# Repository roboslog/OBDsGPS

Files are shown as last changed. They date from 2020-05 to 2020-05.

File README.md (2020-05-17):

# OBDsGPS

OBD ii GPS tracker is the most convenient vehicle GPS tracking device. This tracker plugs into a vehicle’s OBD II port for easy installation. The OBD ii tracker installs within seconds and runs itself. OBD tracker can be used in any car or van manufactured after 2000.

Why we need OBD?

SPEED ALERT BETA
 “The device can be set to alert you when the vehicle exceeds the posted speed limit of whatever road it is currently travelling on.

SPEED THRESHOLD
 The device can be set to alert you whenever the vehicle exceeds a certain speed.

HARSH BRAKING
 The device tracks the rate of deceleration of the vehicle, a major indicator of aggressive driving, and alerts you when the vehicle exceeds a safe threshold.

RAPID ACCELERATION
Another major indicator of aggressive driving, the device also tracks the rate of acceleration of the vehicle and alerts you when the vehicle exceeds a safe threshold.”

OBD-II Background
The OBD-II specification is controlled by the Society of Automobile Engineers and defines the method for requesting diagnostic data and provides a list of standard parameters from the engine control unit. The specification was first released in 1979. Today, depending upon the vehicle, the tracker can retrieve values that include: throttle, engine RPM, fuel available. In some vehicles, the device can even retrieve engine diagnostic codes.

Where is my OBD-II Port?
The OBD-II diagnostic port, also known as a Data Link Connector (DLC), is generally located on the driver’s side of the car or truck under the dash. The location will vary between different manufacturers, models, and production years of a car or truck model. 

Testing Tracking Device Installation
With the creation of your account, a username and password were sent to you for our tracking website. Logon to the system and go to the reports section. Run the unit list view report. Check to be sure the tracking device is reporting ignition on/off events.

What else OBD can do ?
1.Read error diagnostic code

2.Clear the fault code (clear the error code and turn off MIL)

3.Engine revolutions per minute (RPM)

4.Calculated load value

5.Coolant temperature

6.Fuel system status

7.Speed

8.Short-term fuel situation

9.Long-term fuel situation

10.Intake manifold pressure

11.Fuel injection advance time

12.Intake air temperature

& Many more….

Our all files & Code here are For Non-Commercial (Educational) use Only, For Commercial Use: Give Credit to ROBOSLOG
Thanks
More updates coming soon..

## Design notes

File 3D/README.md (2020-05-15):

1.Read error diagnostic code
2.Clear the fault code (clear the error code and turn off MIL)
3.Engine revolutions per minute (RPM)
4.Calculated load value
5.Coolant temperature
6.Fuel system status
7.Speed
8.Short-term fuel situation
9.Long-term fuel situation
10.Intake manifold pressure
11.Fuel injection advance time
12.Intake air temperature
13.Air flow rate
14.Throttle absolute position
15.Oxygen detection voltage associated with short-term fuel state
16.Fuel system status
17.Fuel pressure
18.Fuel consumption monitoring, etc.

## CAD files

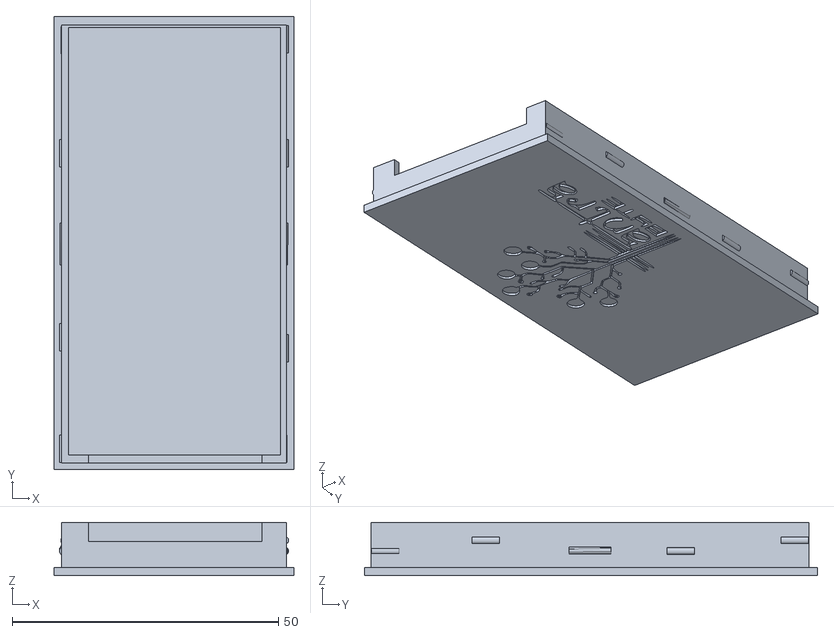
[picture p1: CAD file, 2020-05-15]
3D/obd_topv2.stl
45.0 x 85.0 x 10.0

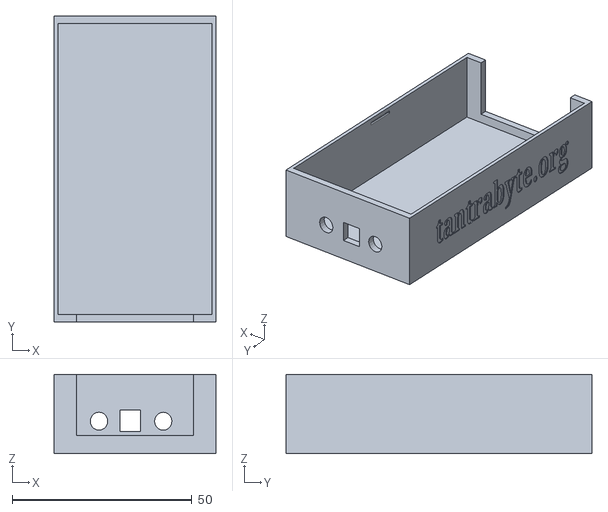
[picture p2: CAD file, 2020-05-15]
3D/obd_bootom v2.stl
45.0 x 85.0 x 22.0

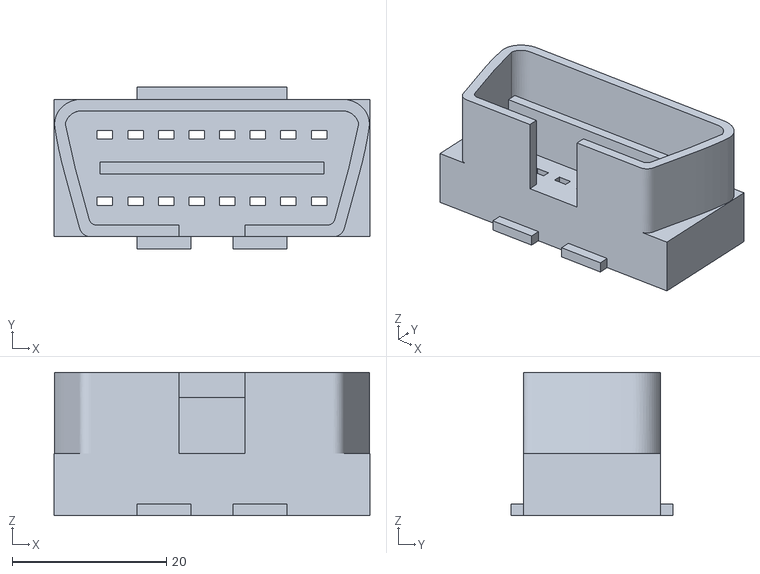
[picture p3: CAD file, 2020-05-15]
3D/OBD.stl
40.9 x 21.0 x 18.5

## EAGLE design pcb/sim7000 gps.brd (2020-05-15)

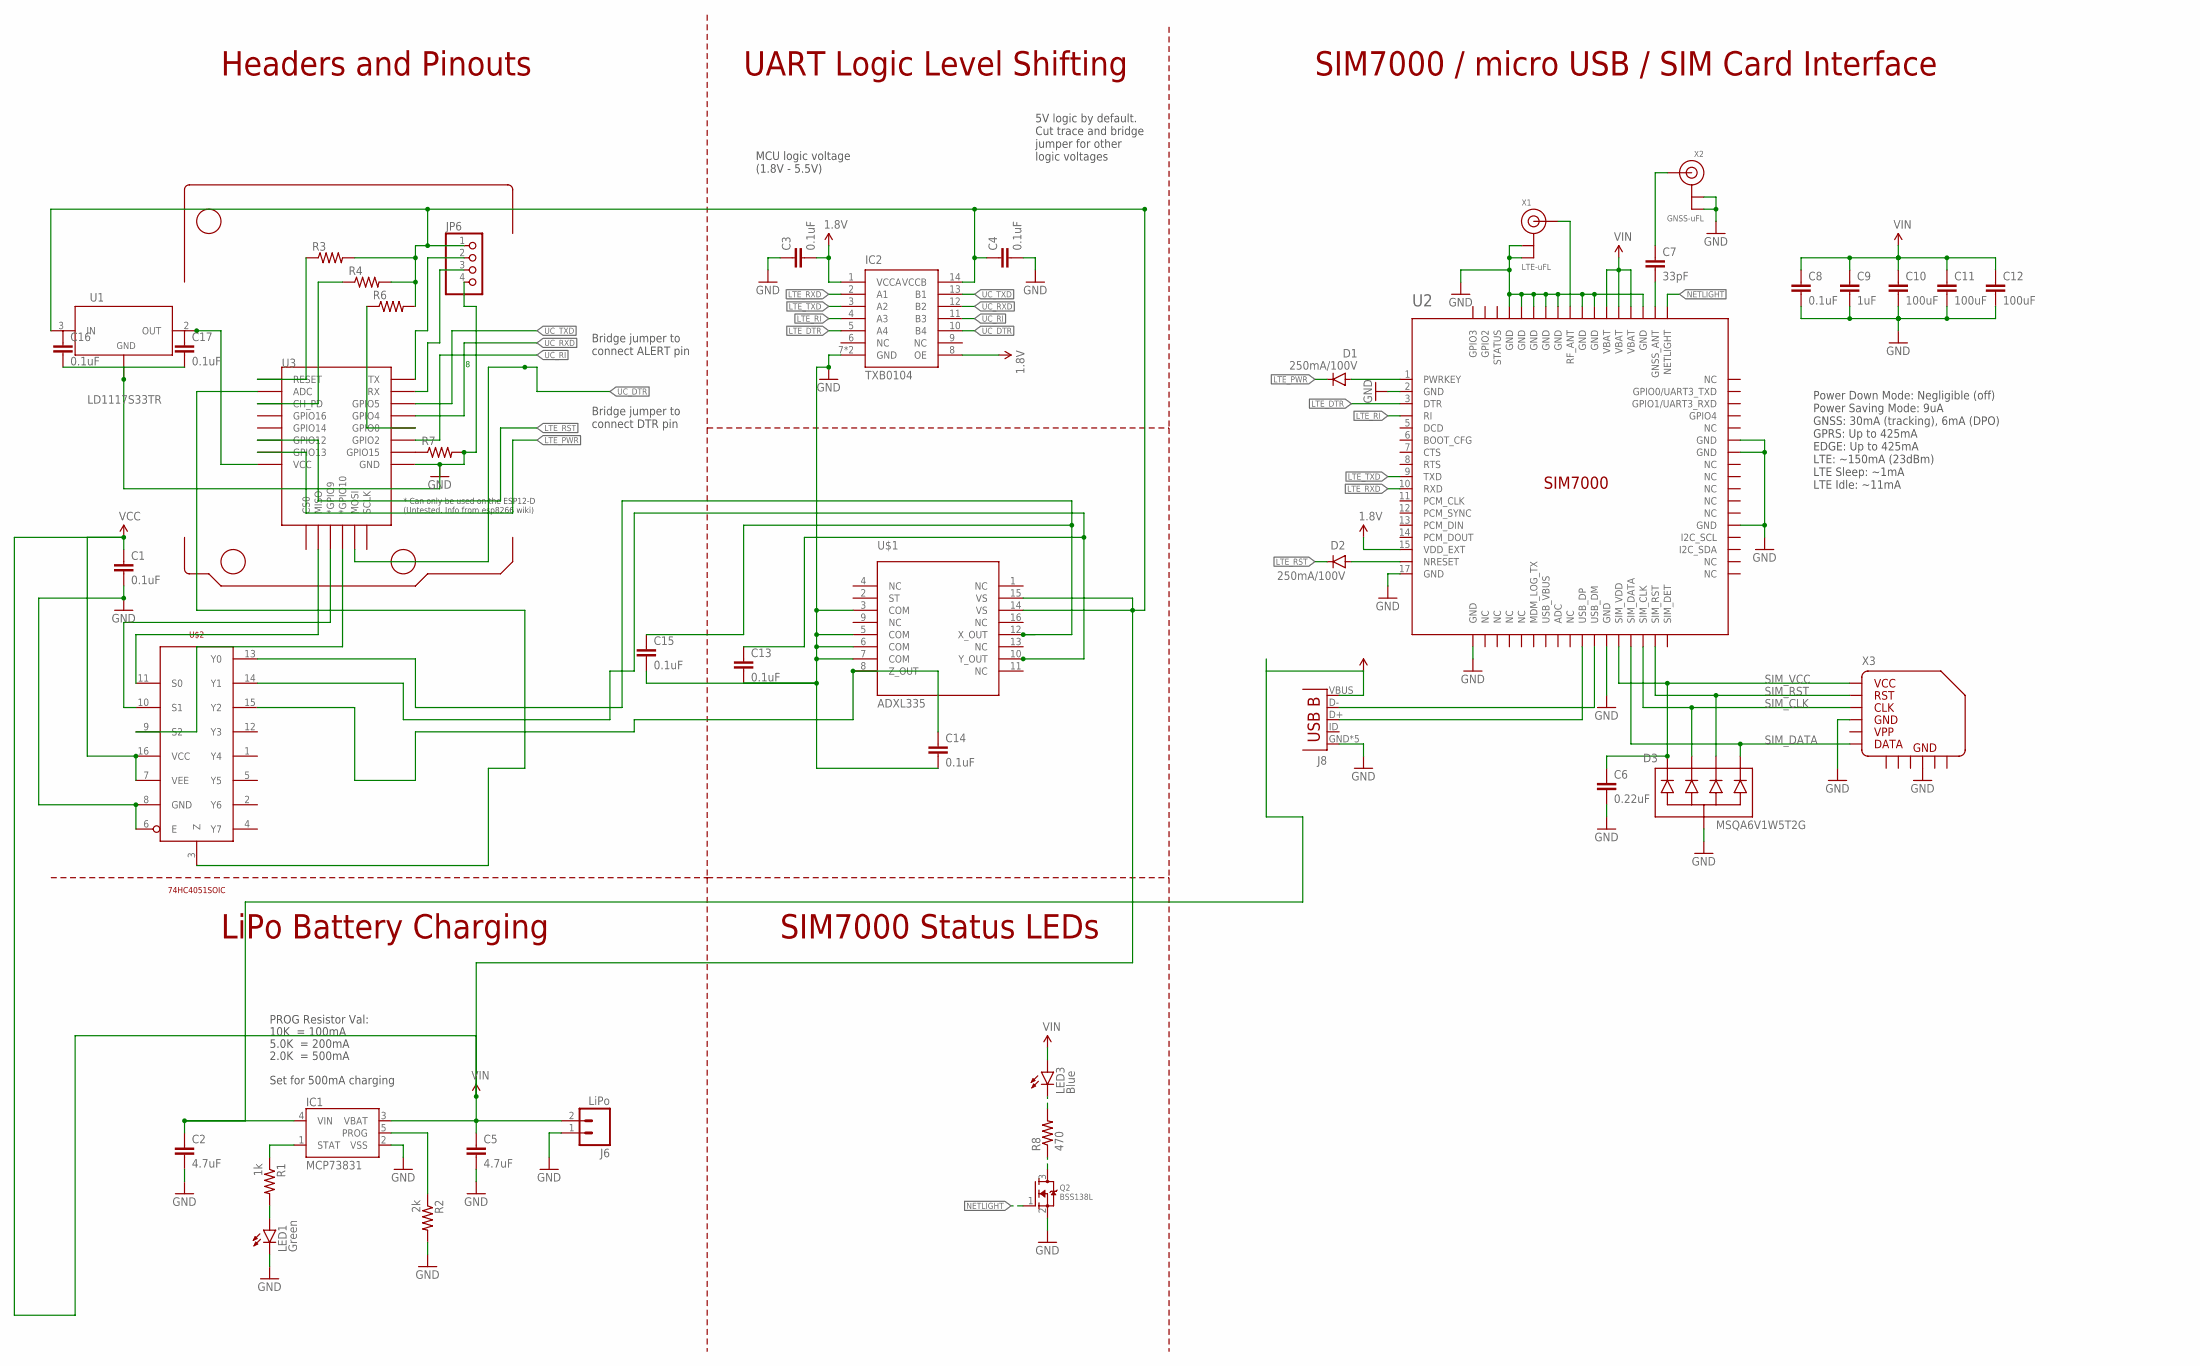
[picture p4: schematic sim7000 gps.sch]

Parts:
C1, C16, C17: 0.1uF; 0603
C2, C5: 4.7uF; 0603-CAP-MARKED
C3, C4, C8, C13, C14, C15: 0.1uF; 0603-CAP-MARKED
C6: 0.22uF; 0603-CAP-MARKED
C7: 33pF; 0603-CAP-MARKED
C9: 1uF; 0603-CAP-MARKED
C10, C11, C12: 100uF; 1210
D1, D2: 250mA/100V; SOD-323
D3: MSQA6V1W5T2G; SOT-353
IC1: MCP73831; SOT23-5
IC2: TXB0104; VQFN-14
J6: LiPo; JST-2-SMD
J8: microUSB; USB-B-MICRO-SMD
JP6: PINHD-1X4; 1X04
LED1: Green; LED-0603-MARKED
LED3: Blue; LED-0603-MARKED
Q2: BSS138L; SOT23-3
R1: 1k; 0603-RES-MARKED
R2: 2k; 0603-RES-MARKED
R3, R4, R6, R7: R-US_R0603; R0603
R8: 470; 0603-RES-MARKED
U1: LD1117S33TR; SOT-223
U2: SIM7000
U3: ESP12ESMD; ESP12E-SMD
U$1: ADXL335; LFCSP16
U$2: 74HC4051SOIC; SOIC-16_3.9MM
X1: LTE-uFL; U.FL
X2: GNSS-uFL; U.FL
X3: MICROSIM_SOCKET_PUSH-PULL

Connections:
1.8V: C3.2, IC2.1 (VCCA), IC2.8 (OE), U2.15 (VDD_EXT)
GND: C1.2, C2.2, C3.1, C4.2, C5.2, C6.2, C8.2, C9.2, C10.2, C11.2, C12.2, C13.2, C14.2, C15.2, C16.2, C17.2, D3.2 (COM), IC1.2 (VSS), IC2.7 (GND), IC2.PAD (GND), J6.1 (2), J8.GND, J8.SHIELD1 (GND), J8.SHIELD2 (GND), J8.SHIELD3 (GND), J8.SHIELD4 (GND), JP6.4, LED1.C, Q2.2 (S), R2.2, R7.2, U1.1 (ADJ/GND), U2.2 (GND), U2.17 (GND), U2.18 (GND), U2.29 (GND), U2.39 (GND), U2.45 (GND), U2.46 (GND), U2.54 (GND), U2.58 (GND), U2.59 (GND), U2.61 (GND), U2.62 (GND), U2.63 (GND), U2.64 (GND), U2.65 (GND), U3.GND, U$1.3 (COM), U$1.5 (COM), U$1.6 (COM), U$1.7 (COM), U$2.6 (E), U$2.8 (GND), X1.1 (GND), X1.2 (GND), X2.1 (GND), X2.2 (GND), X3.C5, X3.GND@1 (GND), X3.GND@2 (GND), X3.GND@3 (GND), X3.GND@4 (GND), X3.GND@5 (GND), X3.GND@6 (GND)
LTE_DTR: IC2.5 (A4), U2.3 (DTR)
LTE_PWR: D1.C, U3.GPIO13
LTE_RI: IC2.4 (A3), U2.4 (RI)
LTE_RST: D2.C, U3.GPIO12
LTE_RXD: IC2.2 (A1), U2.10 (RXD)
LTE_TXD: IC2.3 (A2), U2.9 (TXD)
unnamed: C7.2, U2.53 (GNSS_ANT)
unnamed: D1.A, U2.1 (PWRKEY)
unnamed: C7.1, X2.3 (SIGNAL)
unnamed: U3.MISO, U$2.11 (S0)
unnamed: U3.GPIO9 (*GPIO9), U$2.10 (S1)
unnamed: R7.1, U3.GPIO15
unnamed: J8.D-, U2.28 (USB_DM)
unnamed: J8.D+, U2.27 (USB_DP)
unnamed: Q2.3 (D), R8.1
unnamed: LED3.C, R8.2
unnamed: U3.GPIO10 (*GPIO10), U$2.9 (S2)
unnamed: R3.1, U3.RESET
unnamed: LED1.A, R1.2
unnamed: R4.1, U3.CH_PD
unnamed: C14.1, U$1.8 (Z_OUT), U$2.15 (Y2)
unnamed: U1.2 (OUT), U1.4, U3.VCC
unnamed: R6.1, U3.GPIO0
unnamed: C13.1, U$1.10 (Y_OUT), U$2.14 (Y1)
unnamed: C15.1, U$1.12 (X_OUT), U$2.13 (Y0)
unnamed: JP6.2, U3.TXD0 (TX)
unnamed: JP6.3, U3.RXD0 (RX)
unnamed: U3.ADC, U$2.3 (Z)
NETLIGHT: Q2.1 (G), U2.52 (NETLIGHT)
NRESET: D2.A, U2.16 (NRESET)
PROG: IC1.5 (PROG), R2.1
RF_ANT: U2.60 (RF_ANT), X1.3 (SIGNAL)
SIM_CLK: D3.3 (2), U2.32 (SIM_CLK), X3.C3
SIM_DATA: D3.5 (4), U2.31 (SIM_DATA), X3.C7
SIM_RST: D3.4 (3), U2.33 (SIM_RST), X3.C2
SIM_VCC: C6.1, D3.1, U2.30 (SIM_VDD), X3.C1
STAT: IC1.1 (STAT), R1.1
UC_DTR: IC2.10 (B4), U3.MOSI
UC_RI: IC2.11 (B3), U3.GPIO2
UC_RXD: IC2.12 (B2), U3.GPIO4
UC_TXD: IC2.13 (B1), U3.GPIO5
VIN: C1.1, C4.1, C5.1, C8.1, C9.1, C10.1, C11.1, C12.1, IC1.3 (VBAT), IC2.14 (VCCB), J6.2 (1), JP6.1, LED3.A, R3.2, R4.2, R6.2, U1.3 (IN), U2.55 (VBAT), U2.56 (VBAT), U2.57 (VBAT), U$1.14 (VS), U$1.15 (VS), U$2.7 (VEE), U$2.16 (VCC)
V_USB: C2.1, IC1.4 (VIN), J8.VBUS

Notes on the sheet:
SIM7000 / micro USB / SIM Card Interface
Headers and Pinouts
LiPo Battery Charging
UART Logic Level Shifting
SIM7000 Status LEDs
Power Down Mode: Negligible (off) Power Saving Mode: 9uA GNSS: 30mA (tracking), 6mA (DPO) GPRS: Up to 425mA EDGE: Up to 425mA LTE: ~150mA (23dBm) LTE Sleep: ~1mA LTE Idle: ~11mA
Bridge jumper to connect DTR pin
Bridge jumper to connect ALERT pin
MCU logic voltage (1.8V - 5.5V)
5V logic by default. Cut trace and bridge jumper for other logic voltages
Set for 500mA charging
10K = 100mA
5.0K = 200mA
2.0K = 500mA
PROG Resistor Val:

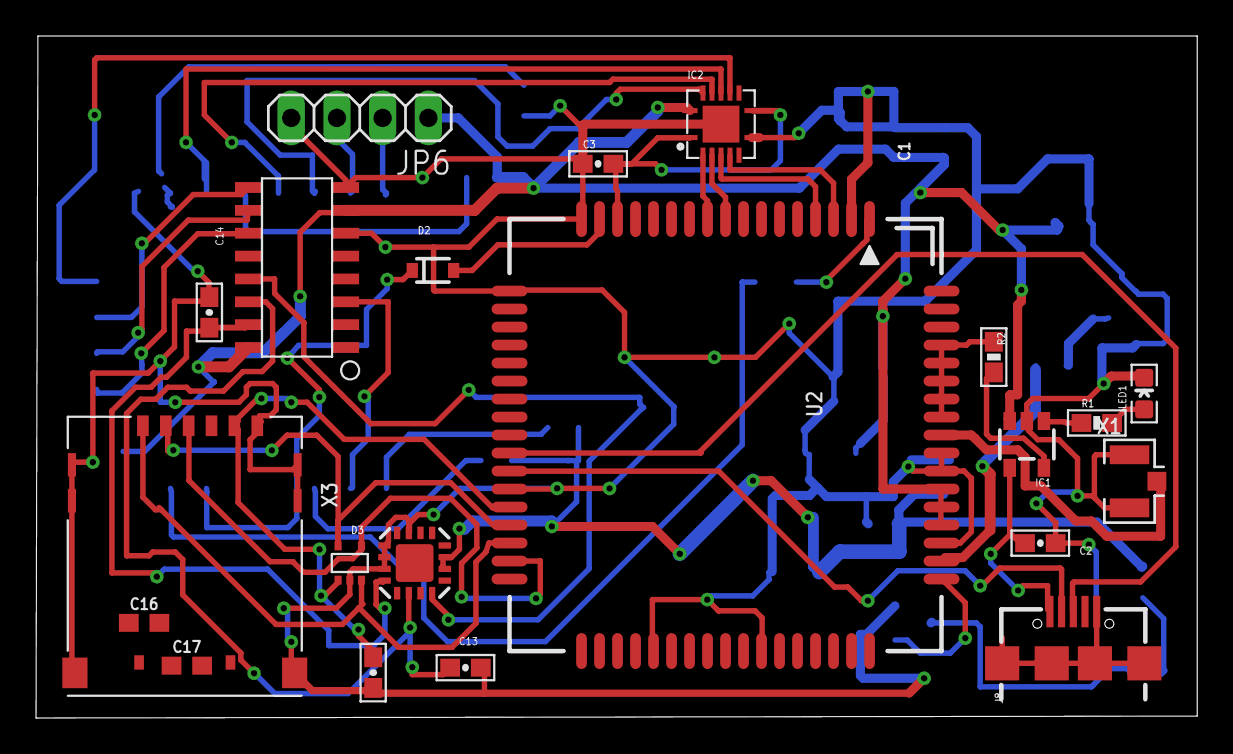
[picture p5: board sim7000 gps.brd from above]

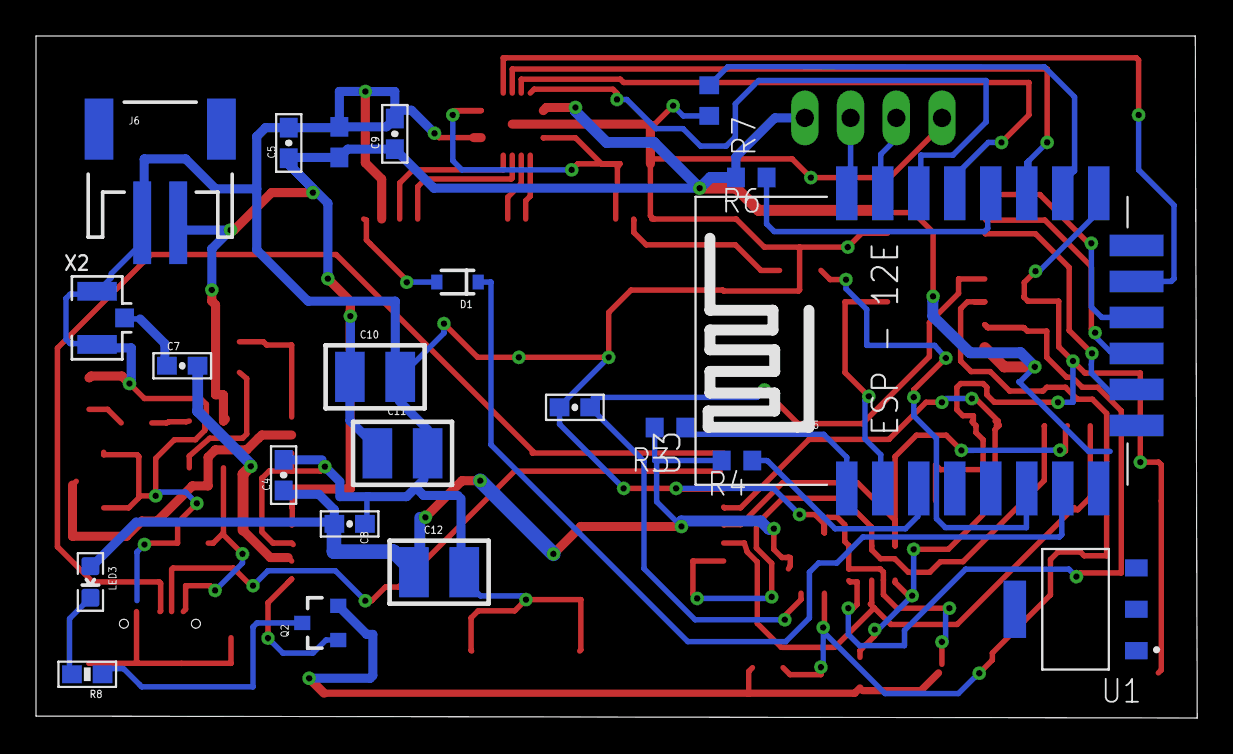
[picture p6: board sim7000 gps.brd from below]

Board: 2 copper layers, 64.5 x 37.9 mm, 43 parts (22 on the bottom side), 45 nets.

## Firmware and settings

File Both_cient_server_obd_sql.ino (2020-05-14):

/*------------------------------------------------------------------------------
  10/04/2020
  Author: Narendok/Kapil @ROBOSLOG TEAM
  Platforms: ESP8266
  Language: C++/Arduino
  File: ObdgpsFinal.ino
------------------------------------------
  Please consider buying products from ROBOSLOF to help fund future
  Open-Source projects like this! We'll always put our best effort in every
  project, and release all our design files and code for you to use.

  https://roboslog.in/agri
  ------------------------------------------------------------------------------
  License:
  Please see attached LICENSE.txt file for details.   
 ----------------------------------------------------------------------------- */
#include <TinyGPS++.h>
#include <SoftwareSerial.h>
#include <WiFiClient.h>
#include <ESP8266WebServer.h>

IPAddress ip(192, 168, 43, 228); //set static ip
IPAddress gateway(192, 168, 43, 1); //set getteway
IPAddress subnet(255, 255, 255, 0);//set subnet
// initialize the library with the numbers of the interface pins
int period =200;
unsigned long time_now = 0;
String elm="";
byte inData;
char inChar;
String BuildINString="";
String DisplayString="";
String WorkingString="";
long DisplayValue;
long A, B,C,D;
bool temp=0;
String 
Gps_Lat="",
Gps_Lon="",
STATUS2="",
FREEZE_DTC="",
FUEL_STATUS="",
ENGINE_LOAD="",
COOLANT_TEMP="",
SHORT_FUEL_TRIM_1="",
LONG_FUEL_TRIM_1="",
SHORT_FUEL_TRIM_2="",
LONG_FUEL_TRIM_2="",
FUEL_PRESSURE="",
INTAKE_PRESSURE="",
RPM="",
SPEED="",
TIMING_ADVANCE="",
INTAKE_TEMP="",
MAF="",
THROTTLE_POS="",
AIR_STATUS="",
O2_SENSORS="",
O2_B1S1="",
O2_B1S2="",
O2_B1S3="",
O2_B1S4="",
O2_B2S1="",
O2_B2S2="",
O2_B2S3="",
O2_B2S4="",
OBD_COMPLIANCE="",
O2_SENSORS_ALT="",
AUX_INPUT_STATUS="",
RUN_TIME="",
DISTANCE_W_MIL="",
FUEL_RAIL_PRESSURE_VAC="",
FUEL_RAIL_PRESSURE_DIRECT="",
O2_S1_WR_VOLTAGE="",
O2_S2_WR_VOLTAGE="",
O2_S3_WR_VOLTAGE="",
O2_S4_WR_VOLTAGE="",
O2_S5_WR_VOLTAGE="",
O2_S6_WR_VOLTAGE="",
O2_S7_WR_VOLTAGE="",
O2_S8_WR_VOLTAGE="",
COMMANDED_EGR="",
EGR_ERROR="",
EVAPORATIVE_PURGE="",
FUEL_LEVEL="",
WARMUPS_SINCE_DTC_CLEAR="",
DISTANCE_SINCE_DTC_CLEAR="",
EVAP_VAPOR_PRESSURE="",
BAROMETRIC_PRESSURE="",
O2_S1_WR_CURRENT="",
O2_S2_WR_CURRENT="",
O2_S3_WR_CURRENT="",
O2_S4_WR_CURRENT="",
O2_S5_WR_CURRENT="",
O2_S6_WR_CURRENT="",
O2_S7_WR_CURRENT="",
O2_S8_WR_CURRENT="",
CATALYST_TEMP_B1S1="",
CATALYST_TEMP_B2S1="",
CATALYST_TEMP_B1S2="",
CATALYST_TEMP_B2S2="",
STATUS_DRIVE_CYCLE="",
CONTROL_MODULE_VOLTAGE="",
ABSOLUTE_LOAD="",
COMMANDED_EQUIV_RATIO="",
RELATIVE_THROTTLE_POS="",
AMBIANT_AIR_TEMP="",
THROTTLE_POS_B="",
THROTTLE_POS_C="",
ACCELERATOR_POS_D="",
ACCELERATOR_POS_E="",
ACCELERATOR_POS_F="",
THROTTLE_ACTUATOR="",
RUN_TIME_MIL="",
TIME_SINCE_DTC_CLEARED="",
unsupported="",
MAX_MAF="",
FUEL_TYPE="",
ETHANOL_PERCENT="",
EVAP_VAPOR_PRESSURE_ABS="",
EVAP_VAPOR_PRESSURE_ALT="",
SHORT_O2_TRIM_B1="",
LONG_O2_TRIM_B1="",
SHORT_O2_TRIM_B2="",
LONG_O2_TRIM_B2="",
FUEL_RAIL_PRESSURE_ABS="",
RELATIVE_ACCEL_POS="",
HYBRID_BATTERY_REMAINING="",
OIL_TEMP="",
FUEL_INJECT_TIMING="",
FUEL_RATE="",
PID01to20,PID21to40,PID41to60,PID61to80,PID81toA0;
TinyGPSPlus gps;  // The TinyGPS++ object

SoftwareSerial ss(4,5); // The serial connection to the GPS device
//SoftwareSerial s(D5, D6); // 

const char* ssid = "Robo";
const char* password = "lopklopk";
const char* host = "gpsobd.000webhostapp.com";

float latitude , longitude;
int year , month , date, hour , minute , second;
String date_str , time_str , lat_str , lng_str;
bool pm;
char buff[32];
String Dev_ID="RSSS101";
 WiFiServer server(80); 
void setup()
{
  Serial1.begin(115200);
  ss.begin(9600);
  Serial.begin(38400);
  //Serial.println();
//  Serial.print("Connecting to ");
  //Serial.println(ssid);
    WiFi.config(ip, gateway, subnet);
  WiFi.begin(ssid, password);

  while (WiFi.status() != WL_CONNECTED)
  {
    delay(500);
 Serial1.print(".");
  }
//  Serial.println("");
 Serial1.println("WiFi connected");

delay(1000);
//  lcd.clear();

//********************************************************************
  
  //Set up s communication at 9600 baud
  Serial.begin(38400);   //initialize  
  
server.begin();

 Serial.println("Server started");

  // Print the IP address
 // Serial.println(WiFi.localIP());
  retry:
Serial.println("atz");
 
  time_now = millis();
while(millis()< time_now + period)
{
  Gp();
  Up();
}
  // Serial.println("reading...      ");
  ReadData();
   Serial1.println(BuildINString);                                           // If used substring(1,4)=="ATZ" needed a space before ATZ in Serial Monitor and it did not work
if (BuildINString.indexOf("EL")>=0)    
{
   Serial1.println("Elm Connected");
    elm="Connected";
    temp=1;
 // digitalWrite(D4,0);
    }
    
    else
    {
  Serial1.println("No connected");
  // digitalWrite(D4,1);
   elm="Not_Conn";
   temp=0;
   goto retry;
    }
    
  Serial.println("ATSP0");
Serial1.println("Auto searching protocol");
  time_now = millis();
while(millis()< time_now + period)
{
  Gp();
  Up();
}
  ReadData();
  Serial1.println(BuildINString);

Serial.println("01 00");
time_now = millis();
while(millis()< time_now + period)
{
  Gp();
  Up();
}
 ReadData();
  Serial1.println(BuildINString);
   if(BuildINString.length()<50)
  WorkingString = BuildINString.substring(13, 23);
  else
   WorkingString = BuildINString.substring(41, 52);
Serial1.println(WorkingString);
  WorkingString.replace(" ", "");
  Serial1.println(WorkingString);
  B = strtoul(WorkingString.c_str(), NULL, 16);
   Serial1.println(B);
 PID01to20= itoa(B,buff,2);
  Serial1.println(PID01to20);
   // Creating array of string length  
   
}

void loop()

{
  
 Serial.println("01 01");
time_now = millis();
while(millis()< time_now + period)
{
  Gp();
  Up();
}
  ReadData();
  Serial1.println(BuildINString);
   if(BuildINString.length()<22)
  WorkingString = BuildINString.substring(13, 15);
  else
   WorkingString = BuildINString.substring(27, 29);

  A = strtol(WorkingString.c_str(), NULL, 16);
   DisplayValue = A;
   STATUS2 = String(DisplayValue);
   

 Serial.println("01 02");
time_now = millis();
while(millis()< time_now + period)
{
  Gp();
  Up();
}
 ReadData();
  Serial1.println(BuildINString);
    if(BuildINString.length()<22)
  WorkingString = BuildINString.substring(13, 15);
  else
   WorkingString = BuildINString.substring(27, 29);

  A = strtol(WorkingString.c_str(), NULL, 16);
   DisplayValue = A;
   FREEZE_DTC = String(DisplayValue);


 Serial.println("01 03");
time_now = millis();
while(millis()< time_now + period)
{
  Gp();
  Up();
}
 ReadData();
  Serial1.println(BuildINString);
    if(BuildINString.length()<22)
  WorkingString = BuildINString.substring(13, 15);
  else
   WorkingString = BuildINString.substring(27, 29);

  A = strtol(WorkingString.c_str(), NULL, 16);
   DisplayValue = A;
   FUEL_STATUS = String(DisplayValue);


 Serial.println("01 04");
time_now = millis();
while(millis()< time_now + period)
{
  Gp();
  Up();
}
 ReadData();
  Serial1.println(BuildINString);
    if(BuildINString.length()<22)
  WorkingString = BuildINString.substring(13, 15);
  else
   WorkingString = BuildINString.substring(27, 29);
Serial1.println(WorkingString);
  A = strtol(WorkingString.c_str(), NULL, 16);
   DisplayValue = A/2.55;
   ENGINE_LOAD = String(DisplayValue);


   Serial.println("01 05");
time_now = millis();
while(millis()< time_now + period)
{
  Gp();
  Up();
}
 ReadData();
  Serial1.println(BuildINString);
     if(BuildINString.length()<22)
  WorkingString = BuildINString.substring(13, 15);
  else
   WorkingString = BuildINString.substring(27, 29);
   Serial1.println(WorkingString);
    A = strtol(WorkingString.c_str(),NULL,16);
   DisplayValue = A-40;
   COOLANT_TEMP = String(DisplayValue);

   Serial.println("01 06");
time_now = millis();
while(millis()< time_now + period)
{
  Gp();
  Up();
}
 ReadData();
  Serial1.println(BuildINString);
    if(BuildINString.length()<22)
  WorkingString = BuildINString.substring(13, 15);
  else
   WorkingString = BuildINString.substring(27, 29);

  A = strtol(WorkingString.c_str(), NULL, 16);
   DisplayValue = (A-128)*100/128;
   SHORT_FUEL_TRIM_1 = String(DisplayValue);


      Serial.println("01 07");
time_now = millis();
while(millis()< time_now + period)
{
  Gp();
  Up();
}
 ReadData();
  Serial1.println(BuildINString);
    if(BuildINString.length()<22)
  WorkingString = BuildINString.substring(13, 15);
  else
   WorkingString = BuildINString.substring(27, 29);

  A = strtol(WorkingString.c_str(), NULL, 16);
   DisplayValue = (A-128)*100/128;
   LONG_FUEL_TRIM_1 = String(DisplayValue);


      Serial.println("01 08");
time_now = millis();
while(millis()< time_now + period)
{
  Gp();
  Up();
}
 ReadData();
  Serial1.println(BuildINString);
    if(BuildINString.length()<22)
  WorkingString = BuildINString.substring(13, 15);
  else
   WorkingString = BuildINString.substring(27, 29);

  A = strtol(WorkingString.c_str(), NULL, 16);
   DisplayValue = (A-128)*100/128;
   SHORT_FUEL_TRIM_2 = String(DisplayValue);



      Serial.println("01 09");
time_now = millis();
while(millis()< time_now + period)
{
  Gp();
  Up();
}
 ReadData();
  Serial1.println(BuildINString);
    if(BuildINString.length()<22)
  WorkingString = BuildINString.substring(13, 15);
  else
   WorkingString = BuildINString.substring(27, 29);

  A = strtol(WorkingString.c_str(), NULL, 16);
   DisplayValue = (A-128)*100/128;
   LONG_FUEL_TRIM_2 = String(DisplayValue);
   


   Serial.println("01 0A");
time_now = millis();
while(millis()< time_now + period)
{
  Gp();
  Up();
}
 ReadData();
  Serial1.println(BuildINString);
    if(BuildINString.length()<22)
  WorkingString = BuildINString.substring(13, 15);
  else
   WorkingString = BuildINString.substring(27, 29);

  A = strtol(WorkingString.c_str(), NULL, 16);
   DisplayValue = A*3;
   FUEL_PRESSURE = String(DisplayValue);

   
   Serial.println("01 0B");
time_now = millis();
while(millis()< time_now + period)
{
  Gp();
  Up();
}
 ReadData();
  Serial1.println(BuildINString);
    if(BuildINString.length()<22)
  WorkingString = BuildINString.substring(13, 15);
  else
   WorkingString = BuildINString.substring(27, 29);

  A = strtol(WorkingString.c_str(), NULL, 16);
   DisplayValue = A;
   INTAKE_PRESSURE = String(DisplayValue);
   
////////////////////////////////////////// Need RPM & speed to be copy paste

   Serial.println("01 0C");
time_now = millis();
while(millis()< time_now + period)
{
  Gp();
  Up();
}
 ReadData();
  Serial1.println(BuildINString);
  if(BuildINString.length()<25)
  {
  WorkingString = BuildINString.substring(13, 15);
  Serial1.println(WorkingString);
   A = strtol(WorkingString.c_str(), NULL, 16);
  WorkingString = BuildINString.substring(16, 18);
    Serial1.println(WorkingString);
   B = strtol(WorkingString.c_str(), NULL, 16);
  
  }
  else
  { 
     WorkingString = BuildINString.substring(27, 29);
     Serial1.println(WorkingString);
   A = strtol(WorkingString.c_str(), NULL, 16);
  WorkingString = BuildINString.substring(30, 32);
  Serial1.println(WorkingString);
   B = strtol(WorkingString.c_str(), NULL, 16);
  }

   DisplayValue = ((A * 256)+B)/4;
   RPM = String(DisplayValue);

Serial.println("01 0D");
time_now = millis();
while(millis()< time_now + period)
{
  Gp();
  Up();
}
 ReadData();
  Serial1.println(BuildINString);
    if(BuildINString.length()<22)
  WorkingString = BuildINString.substring(13, 15);
  else
   WorkingString = BuildINString.substring(27, 29);

  A = strtol(WorkingString.c_str(), NULL, 16);
   DisplayValue = A;
   SPEED = String(DisplayValue);
   
   Serial.println("01 0E");
time_now = millis();
while(millis()< time_now + period)
{
  Gp();
  Up();
}
 ReadData();
  Serial1.println(BuildINString);
    if(BuildINString.length()<22)
  WorkingString = BuildINString.substring(13, 15);
  else
   WorkingString = BuildINString.substring(27, 29);

  A = strtol(WorkingString.c_str(), NULL, 16);
   DisplayValue = A/2-64;
   TIMING_ADVANCE = String(DisplayValue);
 


   Serial.println("01 0F");
time_now = millis();
while(millis()< time_now + period)
{
  Gp();
  Up();
}
 ReadData();
  Serial1.println(BuildINString);
    if(BuildINString.length()<22)
  WorkingString = BuildINString.substring(13, 15);
  else
   WorkingString = BuildINString.substring(27, 29);

  A = strtol(WorkingString.c_str(), NULL, 16);
   DisplayValue = A-40;
   INTAKE_TEMP = String(DisplayValue);
  




   Serial.println("01 10");
time_now = millis();
while(millis()< time_now + period)
{
  Gp();
  Up();
}
 ReadData();
  Serial1.println(BuildINString);
  if(BuildINString.length()<25)
  {
  WorkingString = BuildINString.substring(13, 15);
   A = strtol(WorkingString.c_str(), NULL, 16);
  WorkingString = BuildINString.substring(16, 18);
   B = strtol(WorkingString.c_str(), NULL, 16);
  
  }
  else
  { 
     WorkingString = BuildINString.substring(27, 29);
   A = strtol(WorkingString.c_str(), NULL, 16);
  WorkingString = BuildINString.substring(30, 32);
   B = strtol(WorkingString.c_str(), NULL, 16);
  }
   DisplayValue = ((A * 256)+B)/4;
   MAF = String(DisplayValue);
  




   Serial.println("01 11");
time_now = millis();
while(millis()< time_now + period)
{
  Gp();
  Up();
}
 ReadData();
  Serial1.println(BuildINString);
    if(BuildINString.length()<22)
  WorkingString = BuildINString.substring(13, 15);
  else
   WorkingString = BuildINString.substring(27, 29);

  A = strtol(WorkingString.c_str(), NULL, 16);
   DisplayValue = A/2.55;
   THROTTLE_POS = String(DisplayValue);
  


   Serial.println("01 12");
time_now = millis();
while(millis()< time_now + period)
{
  Gp();
  Up();
}
 ReadData();
  Serial1.println(BuildINString);
    if(BuildINString.length()<22)
  WorkingString = BuildINString.substring(13, 15);
  else
   WorkingString = BuildINString.substring(27, 29);

  A = strtol(WorkingString.c_str(), NULL, 16);
   DisplayValue = A/2-64;
   AIR_STATUS = String(DisplayValue);
  




   Serial.println("01 13");
time_now = millis();
while(millis()< time_now + period)
{
  Gp();
  Up();
}
 ReadData();
  Serial1.println(BuildINString);
    if(BuildINString.length()<22)
  WorkingString = BuildINString.substring(13, 15);
  else
   WorkingString = BuildINString.substring(27, 29);

  A = strtol(WorkingString.c_str(), NULL, 16);
   DisplayValue = A/2-64;
   O2_SENSORS = String(DisplayValue);
  



   Serial.println("01 14");
time_now = millis();
while(millis()< time_now + period)
{
  Gp();
  Up();
}
 ReadData();
  Serial1.println(BuildINString);
  if(BuildINString.length()<25)
  {
  WorkingString = BuildINString.substring(13, 15);
   A = strtol(WorkingString.c_str(), NULL, 16);
  WorkingString = BuildINString.substring(16, 18);
   B = strtol(WorkingString.c_str(), NULL, 16);
  
  }
  else
  { 
     WorkingString = BuildINString.substring(27, 29);
   A = strtol(WorkingString.c_str(), NULL, 16);
  WorkingString = BuildINString.substring(30, 32);
   B = strtol(WorkingString.c_str(), NULL, 16);
  }
 String volta=String(A/200);
 String stfb=String((B*100/128)-100);
   O2_B1S1 = volta+"volt"+stfb+"%";
  



   Serial.println("01 15");
time_now = millis();
while(millis()< time_now + period)
{
  Gp();
  Up();
}
 ReadData();
  Serial1.println(BuildINString);
  if(BuildINString.length()<25)
  {
  WorkingString = BuildINString.substring(13, 15);
   A = strtol(WorkingString.c_str(), NULL, 16);
  WorkingString = BuildINString.substring(16, 18);
   B = strtol(WorkingString.c_str(), NULL, 16);
  
  }
  else
  { 
     WorkingString = BuildINString.substring(27, 29);
   A = strtol(WorkingString.c_str(), NULL, 16);
  WorkingString = BuildINString.substring(30, 32);
   B = strtol(WorkingString.c_str(), NULL, 16);
  }
  volta=String(A/200);
  stfb=String((B*100/128)-100);
   O2_B1S2 = volta+"volt"+stfb+"%";


   Serial.println("01 16");
time_now = millis();
while(millis()< time_now + period)
{
  Gp();
  Up();
}
 ReadData();
  Serial1.println(BuildINString);
  if(BuildINString.length()<25)
  {
  WorkingString = BuildINString.substring(13, 15);
   A = strtol(WorkingString.c_str(), NULL, 16);
  WorkingString = BuildINString.substring(16, 18);
   B = strtol(WorkingString.c_str(), NULL, 16);
  
  }
  else
  { 
     WorkingString = BuildINString.substring(27, 29);
   A = strtol(WorkingString.c_str(), NULL, 16);
  WorkingString = BuildINString.substring(30, 32);
   B = strtol(WorkingString.c_str(), NULL, 16);
  }
  volta=String(A/200);
  stfb=String((B*100/128)-100);
   O2_B1S3 = volta+"volt"+stfb+"%";


   Serial.println("01 17");
time_now = millis();
while(millis()< time_now + period)
{
  Gp();
  Up();
}
 ReadData();
  Serial1.println(BuildINString);
  if(BuildINString.length()<25)
  {
  WorkingString = BuildINString.substring(13, 15);
   A = strtol(WorkingString.c_str(), NULL, 16);
  WorkingString = BuildINString.substring(16, 18);
   B = strtol(WorkingString.c_str(), NULL, 16);
  
  }
  else
  { 
     WorkingString = BuildINString.substring(27, 29);
   A = strtol(WorkingString.c_str(), NULL, 16);
  WorkingString = BuildINString.substring(30, 32);
   B = strtol(WorkingString.c_str(), NULL, 16);
  }
  volta=String(A/200);
  stfb=String((B*100/128)-100);
   O2_B1S4 = volta+"volt"+stfb+"%";


   Serial.println("01 18");
time_now = millis();
while(millis()< time_now + period)
{
  Gp();
  Up();
}
 ReadData();
  Serial1.println(BuildINString);
  if(BuildINString.length()<25)
  {
  WorkingString = BuildINString.substring(13, 15);
   A = strtol(WorkingString.c_str(), NULL, 16);
  WorkingString = BuildINString.substring(16, 18);
   B = strtol(WorkingString.c_str(), NULL, 16);
  
  }
  else
  { 
     WorkingString = BuildINString.substring(27, 29);
   A = strtol(WorkingString.c_str(), NULL, 16);
  WorkingString = BuildINString.substring(30, 32);
   B = strtol(WorkingString.c_str(), NULL, 16);
  }
  volta=String(A/200);
  stfb=String((B*100/128)-100);
   O2_B2S1 = volta+"volt"+stfb+"%";


   Serial.println("01 19");
time_now = millis();
while(millis()< time_now + period)
{
  Gp();
  Up();
}
 ReadData();
  Serial1.println(BuildINString);
  if(BuildINString.length()<25)
  {
  WorkingString = BuildINString.substring(13, 15);
   A = strtol(WorkingString.c_str(), NULL, 16);
  WorkingString = BuildINString.substring(16, 18);
   B = strtol(WorkingString.c_str(), NULL, 16);
  
  }
  else
  { 
     WorkingString = BuildINString.substring(27, 29);
   A = strtol(WorkingString.c_str(), NULL, 16);
  WorkingString = BuildINString.substring(30, 32);
   B = strtol(WorkingString.c_str(), NULL, 16);
  }
  volta=String(A/200);
  stfb=String((B*100/128)-100);
   O2_B2S2 = volta+"volt"+stfb+"%";
 


   Serial.println("01 1A");
time_now = millis();
while(millis()< time_now + period)
{
  Gp();
  Up();
}
 ReadData();
  Serial1.println(BuildINString);
  if(BuildINString.length()<25)
  {
  WorkingString = BuildINString.substring(13, 15);
   A = strtol(WorkingString.c_str(), NULL, 16);
  WorkingString = BuildINString.substring(16, 18);
   B = strtol(WorkingString.c_str(), NULL, 16);
  
  }
  else
  { 
     WorkingString = BuildINString.substring(27, 29);
   A = strtol(WorkingString.c_str(), NULL, 16);
  WorkingString = BuildINString.substring(30, 32);
   B = strtol(WorkingString.c_str(), NULL, 16);
  }
  volta=String(A/200);
  stfb=String((B*100/128)-100);
   O2_B2S3 = volta+"volt"+stfb+"%";
  


   Serial.println("01 1B");
time_now = millis();
while(millis()< time_now + period)
{
  Gp();
  Up();
}
 ReadData();
  Serial1.println(BuildINString);
  if(BuildINString.length()<25)
  {
  WorkingString = BuildINString.substring(13, 15);
   A = strtol(WorkingString.c_str(), NULL, 16);
  WorkingString = BuildINString.substring(16, 18);
   B = strtol(WorkingString.c_str(), NULL, 16);
  
  }
  else
  { 
     WorkingString = BuildINString.substring(27, 29);
   A = strtol(WorkingString.c_str(), NULL, 16);
  WorkingString = BuildINString.substring(30, 32);
   B = strtol(WorkingString.c_str(), NULL, 16);
  }
  volta=String(A/200);
  stfb=String((B*100/128)-100);
   O2_B2S4 = volta+"volt"+stfb+"%";



   Serial.println("01 1C");
time_now = millis();
while(millis()< time_now + period)
{
  Gp();
  Up();
}
 ReadData();
  Serial1.println(BuildINString);
    if(BuildINString.length()<22)
  WorkingString = BuildINString.substring(13, 15);
  else
   WorkingString = BuildINString.substring(27, 29);

  A = strtol(WorkingString.c_str(), NULL, 16);
   DisplayValue = A/2-64;
   OBD_COMPLIANCE = String(DisplayValue);
  



   Serial.println("01 1D");
time_now = millis();
while(millis()< time_now + period)
{
  Gp();
  Up();
}
 ReadData();
  Serial1.println(BuildINString);
    if(BuildINString.length()<22)
  WorkingString = BuildINString.substring(13, 15);
  else
   WorkingString = BuildINString.substring(27, 29);

  A = strtol(WorkingString.c_str(), NULL, 16);
   DisplayValue = A/2-64;
   O2_SENSORS_ALT = String(DisplayValue);
  



   Serial.println("01 1E");
time_now = millis();
while(millis()< time_now + period)
{
  Gp();
  Up();
}
 ReadData();
  Serial1.println(BuildINString);
    if(BuildINString.length()<22)
  WorkingString = BuildINString.substring(13, 15);
  else
   WorkingString = BuildINString.substring(27, 29);

  A = strtol(WorkingString.c_str(), NULL, 16);
   DisplayValue = A/2-64;
   AUX_INPUT_STATUS = String(DisplayValue);
  



   Serial.println("01 1F");
time_now = millis();
while(millis()< time_now + period)
{
  Gp();
  Up();
}
 ReadData();
  Serial1.println(BuildINString);
 if(BuildINString.length()<25)
  {
  WorkingString = BuildINString.substring(13, 15);
   A = strtol(WorkingString.c_str(), NULL, 16);
  WorkingString = BuildINString.substring(16, 18);
   B = strtol(WorkingString.c_str(), NULL, 16);
  
  }
  else
  { 
     WorkingString = BuildINString.substring(27, 29);
   A = strtol(WorkingString.c_str(), NULL, 16);
  WorkingString = BuildINString.substring(30, 32);
   B = strtol(WorkingString.c_str(), NULL, 16);
  }
   DisplayValue = A*256+B;
   RUN_TIME = String(DisplayValue);
  
 ///////////////////////////////////////////////////////////////////////////////////////////////
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

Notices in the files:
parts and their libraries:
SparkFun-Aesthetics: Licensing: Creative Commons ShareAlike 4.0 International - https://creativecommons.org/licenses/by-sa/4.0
